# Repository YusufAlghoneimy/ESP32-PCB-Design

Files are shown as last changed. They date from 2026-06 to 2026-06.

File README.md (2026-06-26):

# ESP32-PCB-Design

4 Layer ESP32-PCB Design done in Kicad9

Reference:
ESP32 datasheet: (https://cdn.sparkfun.com/datasheets/IoT/esp32_datasheet_en.pdf)

Youtube PCB reference: made by morten (https://www.youtube.com/watch?v=b-7bMl6fJio&t=8320s)






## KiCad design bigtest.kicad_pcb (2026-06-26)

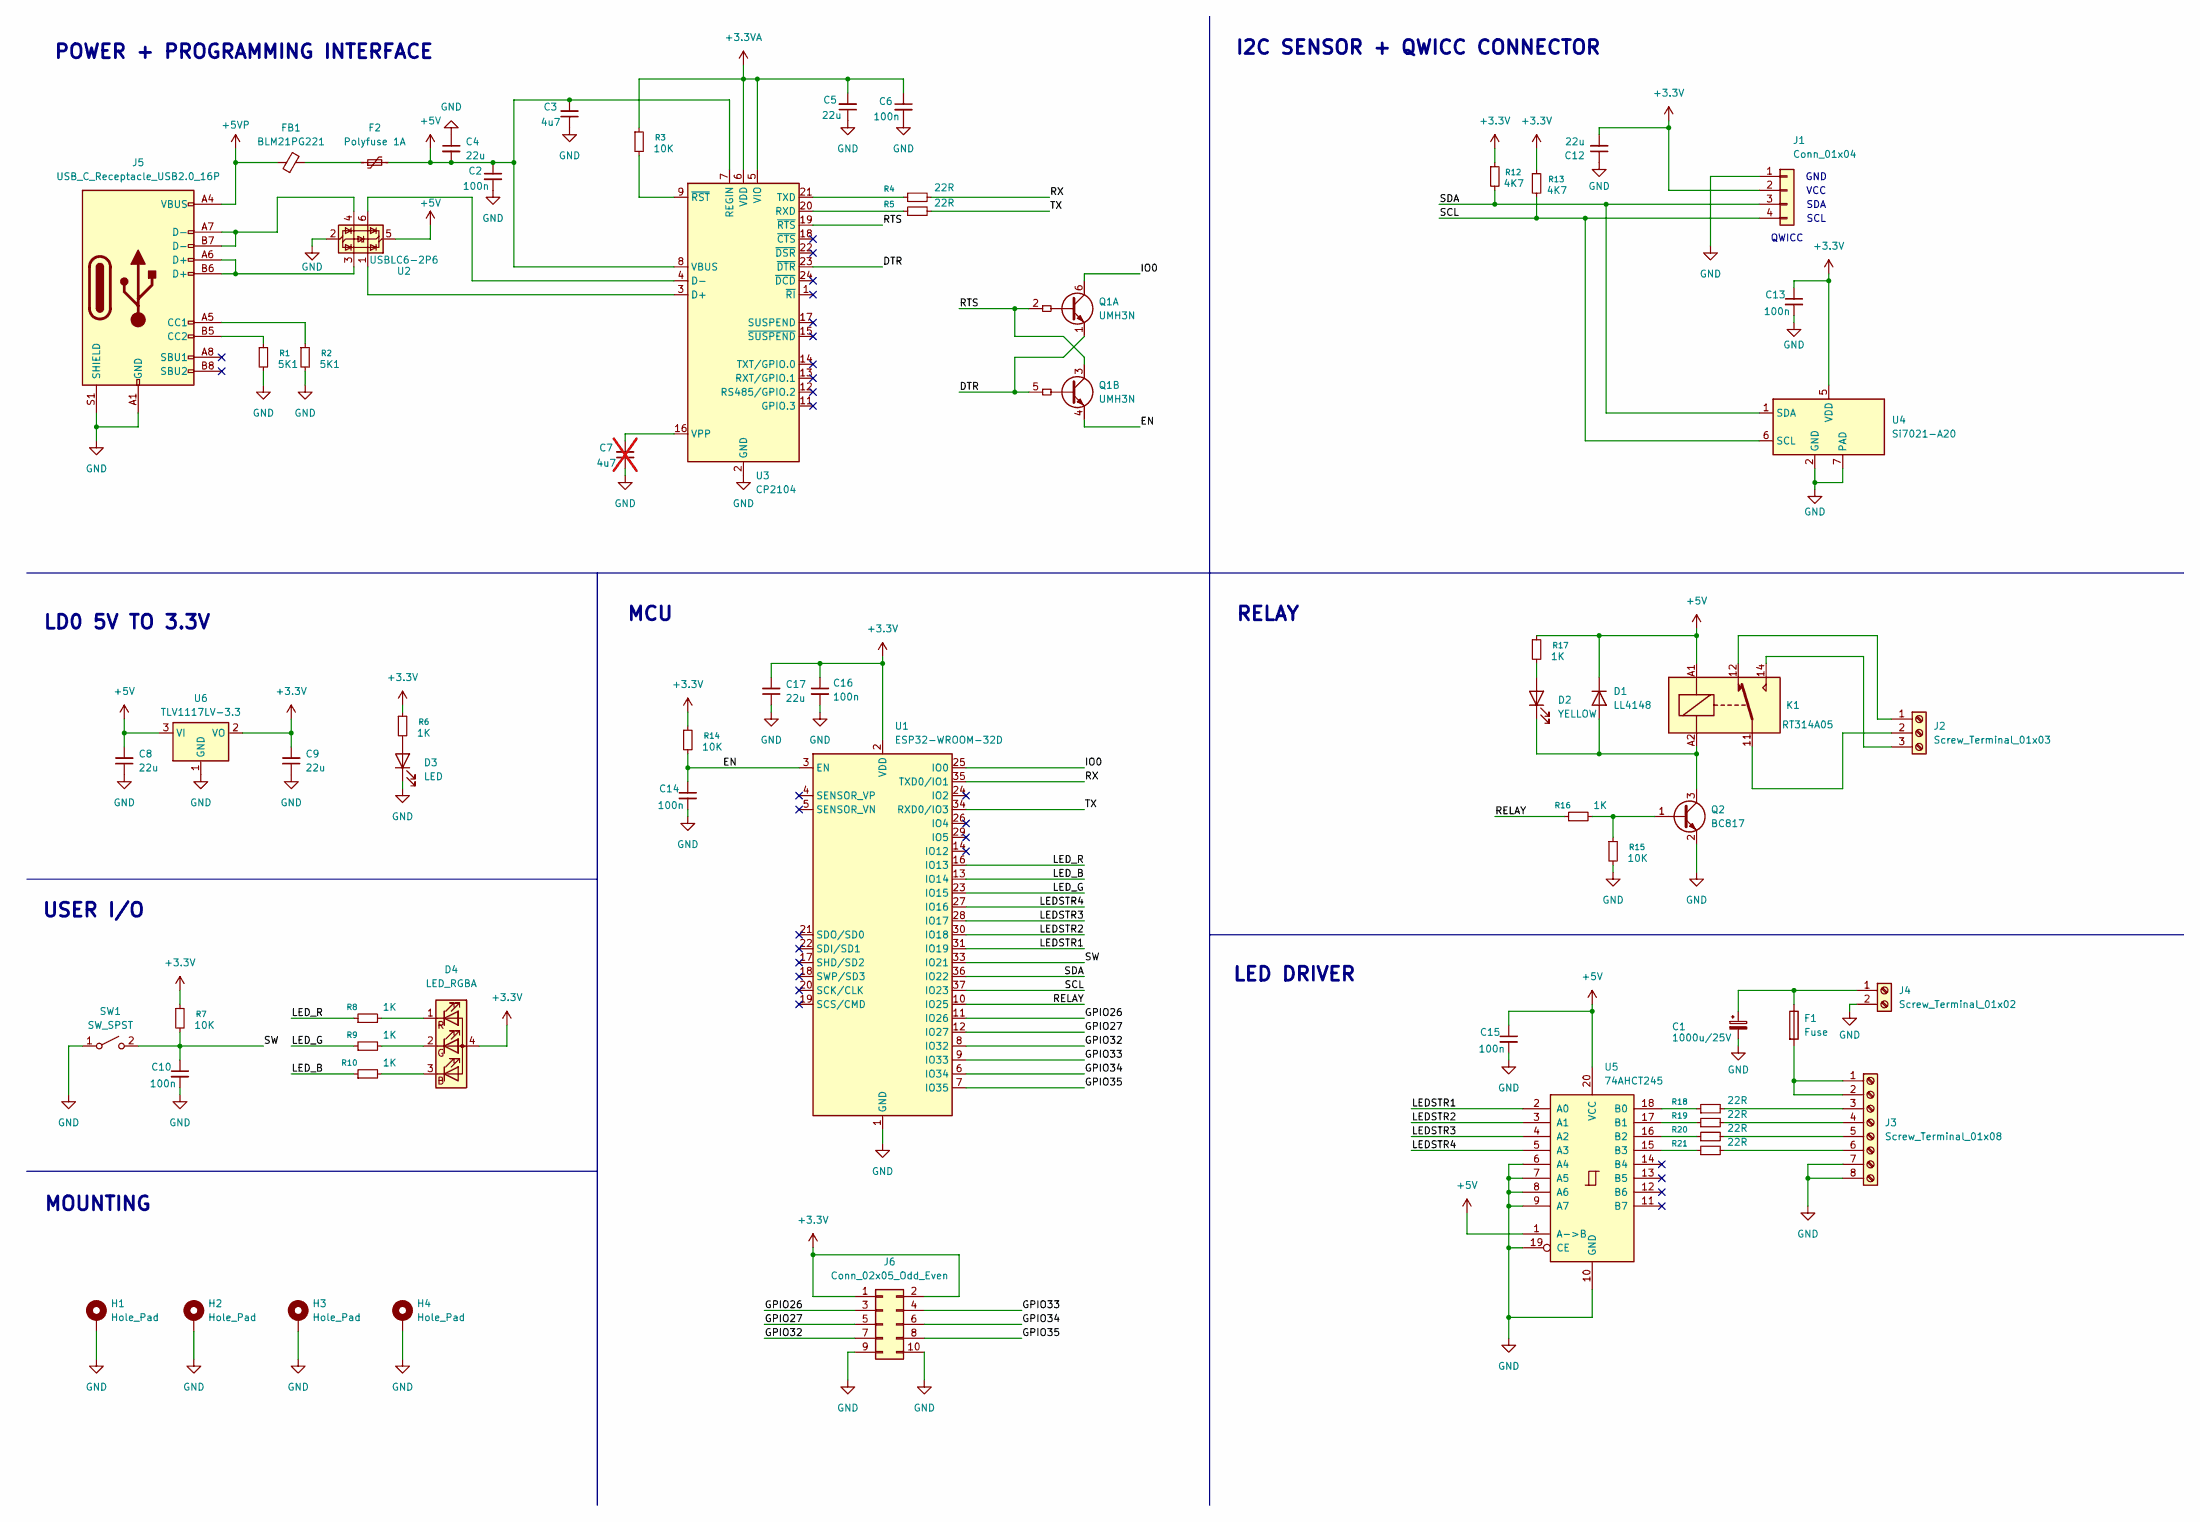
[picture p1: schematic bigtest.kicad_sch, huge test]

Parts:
C1: 1000u/25V; CP_Radial_D10.0mm_P5.00mm
C2, C6, C10, C13, C14, C15, C16: 100n; C_0402_1005Metric_Pad0.74x0.62mm_HandSolder
C3: 4u7; C_0805_2012Metric_Pad1.18x1.45mm_HandSolder
C4, C5, C8, C9, C12, C17: 22u; C_0805_2012Metric_Pad1.18x1.45mm_HandSolder
C7: 4u7; C_0805_2012Metric_Pad1.18x1.45mm_HandSolder; not fitted
D1: LL4148; D_MiniMELF
D2: YELLOW; LED_0603_1608Metric_Pad1.05x0.95mm_HandSolder
D3: LED; LED_0603_1608Metric_Pad1.05x0.95mm_HandSolder
D4: LED_RGBA; LED_RGB_Wuerth-PLCC4_3.2x2.8mm_150141M173100
F1: Fuse; Fuse_0402_1005Metric
F2: Polyfuse 1A; Fuse_1206_3216Metric_Pad1.42x1.75mm_HandSolder
FB1: BLM21PG221; L_0603_1608Metric_Pad1.05x0.95mm_HandSolder
H1, H2, H3, H4: Hole_Pad; MountingHole_3.2mm_M3_Pad_Via
J1: Conn_01x04; JST_SH_SM04B-SRSS-TB_1x04-1MP_P1.00mm_Horizontal
J2: Screw_Terminal_01x03; TerminalBlock_Phoenix_MKDS-3-3-5.08_1x03_P5.08mm_Horizontal
J3: Screw_Terminal_01x08; TerminalBlock_Phoenix_MKDS-1,5-8_1x08_P5.00mm_Horizontal
J4: Screw_Terminal_01x02; TerminalBlock_Phoenix_MKDS-1,5-2-5.08_1x02_P5.08mm_Horizont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
J5: USB_C_Receptacle_USB2.0_16P; USB_C_Receptacle_HRO_TYPE-C-31-M-12
J6: Conn_02x05_Odd_Even; PinHeader_2x05_P2.54mm_Vertical
K1: RT314A05; Relay_SPDT_Schrack-RT1-16A-FormC_RM5mm
Q1: UMH3N; SOT-363_SC-70-6
Q2: BC817; SOT-23
R1, R2: 5K1; R_0402_1005Metric_Pad0.72x0.64mm_HandSolder
R3, R7, R14, R15: 10K; R_0402_1005Metric_Pad0.72x0.64mm_HandSolder
R4, R5, R18, R19, R20, R21: 22R; R_0402_1005Metric_Pad0.72x0.64mm_HandSolder
R6, R8, R9, R10, R16, R17: 1K; R_0402_1005Metric_Pad0.72x0.64mm_HandSolder
R12, R13: 4K7; R_0402_1005Metric_Pad0.72x0.64mm_HandSolder
SW1: SW_SPST; SW_Push_1P1T_NO_CK_KSC7xxJ
U1: ESP32-WROOM-32D
U2: USBLC6-2P6; SOT-666
U3: CP2104; QFN-24-1EP_4x4mm_P0.5mm_EP2.6x2.6mm
U4: Si7021-A20; DFN-6-1EP_3x3mm_P1mm_EP1.5x2.4mm
U5: 74AHCT245; DIP-20_W7.62mm
U6: TLV1117LV-3.3; SOT-223-3_TabPin2

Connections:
+3.3V: C9.2, C12.2, C13.1, C16.1, C17.2, D4.4 (A), J1.2, J6.1, J6.2, R6.1, R7.1, R12.1, R13.1, R14.1, U1.2 (VDD), U4.5 (VDD), U6.2 (VO)
+3.3VA: C5.2, C6.1, R3.1, U3.5 (VIO), U3.6 (VDD)
+5V: C2.1, C3.2, C4.2, C8.2, C15.1, D1.1 (K), F2.2, K1.A1, R17.1, U2.5 (VBUS), U3.7 (REGIN), U3.8 (VBUS), U5.1 (A->B), U5.20 (VCC), U6.3 (VI)
+5VP: FB1.1, J5.A4 (VBUS), J5.A9 (VBUS), J5.B4 (VBUS), J5.B9 (VBUS)
/DTR: Q1.1 (E1), Q1.5 (B2), U3.23 (~DTR)
/EN: C14.1, Q1.4 (E2), R14.2, U1.3 (EN)
/GPIO26: J6.3, U1.11 (IO26)
/GPIO27: J6.5, U1.12 (IO27)
/GPIO32: J6.7, U1.8 (IO32)
/GPIO33: J6.4, U1.9 (IO33)
/GPIO34: J6.6, U1.6 (IO34)
/GPIO35: J6.8, U1.7 (IO35)
/IO0: Q1.6 (C1), U1.25 (IO0)
/LEDSTR1: U1.31 (IO19), U5.2 (A0)
/LEDSTR2: U1.30 (IO18), U5.3 (A1)
/LEDSTR3: U1.28 (IO17), U5.4 (A2)
/LEDSTR4: U1.27 (IO16), U5.5 (A3)
/LED_B: R10.1, U1.13 (IO14)
/LED_G: R9.1, U1.23 (IO15)
/LED_R: R8.1, U1.16 (IO13)
/RELAY: R16.1, U1.10 (IO25)
/RTS: Q1.2 (B1), Q1.3 (C2), U3.19 (~RTS)
/RX: R4.2, U1.35 (TXD0/IO1)
/SCL: J1.4, R13.2, U1.37 (IO23), U4.6 (SCL)
/SDA: J1.3, R12.2, U1.36 (IO22), U4.1 (SDA)
/SW: C10.1, R7.2, SW1.2 (B), U1.33 (IO21)
/TX: R5.2, U1.34 (RXD0/IO3)
GND: C1.2, C2.2, C3.1, C4.1, C5.1, C6.2, C7.1, C8.1, C9.1, C10.2, C12.1, C13.2, C14.2, C15.2, C16.2, C17.1, D3.1 (K), H1.1, H2.1, H3.1, H4.1, J1.1, J3.7, J3.8, J4.2, J5.A1 (GND), J5.A12 (GND), J5.B1 (GND), J5.B12 (GND), J5.S1 (SHIELD), J6.9, J6.10, Q2.2 (E), R1.2, R2.2, R15.2, SW1.1 (A), U1.1 (GND), U1.15 (GND), U1.38 (GND), U1.39 (GND), U2.2 (GND), U3.2 (GND), U3.25 (GND), U4.2 (GND), U4.7 (PAD), U5.6 (A4), U5.7 (A5), U5.8 (A6), U5.9 (A7), U5.10 (GND), U5.19 (CE), U6.1 (GND)
unnamed: D1.2 (A), D2.1 (K), K1.A2, Q2.3 (C)
unnamed: D2.2 (A), R17.2
unnamed: D3.2 (A), R6.2
unnamed: D4.3 (BK), R10.2
unnamed: D4.2 (GK), R9.2
unnamed: D4.1 (RK), R8.2
unnamed: F2.1, FB1.2
unnamed: J2.1, K1.12
unnamed: J2.2, K1.11
unnamed: J2.3, K1.14
unnamed: F1.2, J3.1, J3.2
unnamed: J3.3, R18.2
unnamed: J3.4, R19.2
unnamed: J3.5, R20.2
unnamed: J3.6, R21.2
unnamed: C1.1, F1.1, J4.1
unnamed: J5.A5 (CC1), R2.1
unnamed: J5.B5 (CC2), R1.1
unnamed: J5.A6 (D+), J5.B6 (D+), U2.3 (I/O2)
unnamed: J5.A7 (D-), J5.B7 (D-), U2.4 (I/O2)
unnamed: Q2.1 (B), R15.1, R16.2
unnamed: U2.1 (I/O1), U3.3 (D+)
unnamed: U2.6 (I/O1), U3.4 (D-)
unnamed: R5.1, U3.20 (RXD)
unnamed: R4.1, U3.21 (TXD)
unnamed: C7.2, U3.16 (VPP)
unnamed: R3.2, U3.9 (~RST)
unnamed: R18.1, U5.18 (B0)
unnamed: R19.1, U5.17 (B1)
unnamed: R20.1, U5.16 (B2)
unnamed: R21.1, U5.15 (B3)

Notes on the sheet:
RELAY
QWICC
LD0 5V TO 3.3V
POWER + PROGRAMMING INTERFACE
USER I/O
MCU
I2C SENSOR + QWICC CONNECTOR
VCC
SCL
MOUNTING
LED DRIVER
GND
SDA

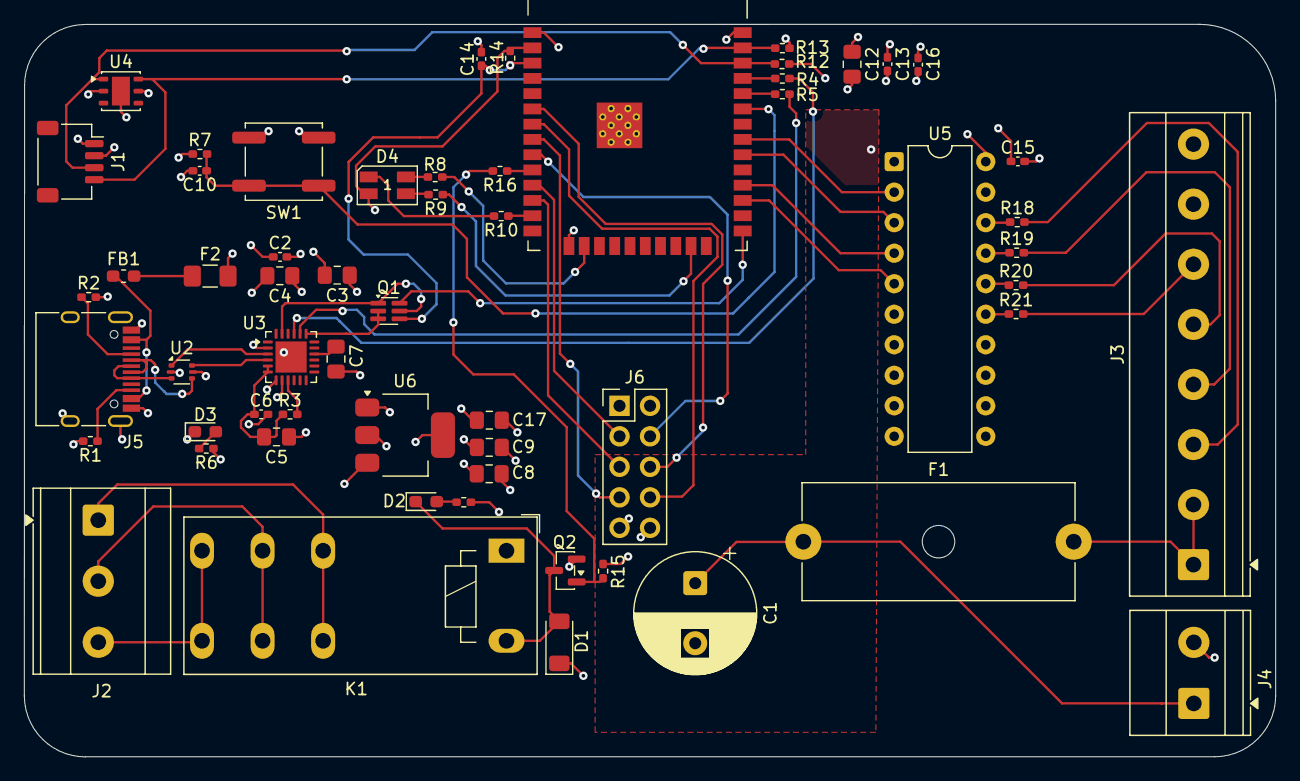
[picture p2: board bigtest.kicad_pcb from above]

Board: 4 copper layers, 104.1 x 61.0 mm, 59 parts (0 on the bottom side), 59 nets.
